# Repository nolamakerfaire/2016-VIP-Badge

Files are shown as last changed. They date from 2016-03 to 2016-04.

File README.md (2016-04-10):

# 2016 VIP Badge


The 2016 New Orleans Mini Maker Faire VIP Badge features an integrated 3.3v 8Mhz Arduino Pro Mini derivative microcontroller and USB FTDI Programmer. The badges come pre-assembled, and feature breakout headers to access the digital and analog pins as well as ground and voltage. Any 3.3v-compatible components can be used with the badge. Additionally, battery packs will be included, but they badge can also be powered by a standard USB cellphone charging battery. Finally, the Arduino Pro Mini derivative and the USB programmer snap out of the badge so you can easily integrate them into future projects.

The badge can be programmed just like a standard [Arduino Pro Mini](https://www.arduino.cc/en/Guide/ArduinoProMini). In the Arduino IDE, select Arduino Pro or Pro Mini (3.3V, 8 MHz) w/ ATmega328 from the Tools > Board menu. 

[Check out our wiki](https://github.com/nolamakerfaire/2016-VIP-Badge/wiki) for some tips on using this board.

Here's a great guide to getting started with the Arduino Pro Mini: [https://learn.sparkfun.com/tutorials/using-the-arduino-pro-mini-33v](https://learn.sparkfun.com/tutorials/using-the-arduino-pro-mini-33v)

If snapped apart, you can solder pin headers onto the USB programmer and use it exactly like the [Sparkfun FTDI Basic Breakout Board](https://www.sparkfun.com/products/9873).

## License Information

The Arduino Pro Mini derivative hardware is released under [Creative Commons Share-alike 3.0](http://creativecommons.org/licenses/by-sa/3.0/).

The FTDI Basic Breakout derivative hardware is released under [Creative Commons ShareAlike 4.0 International](https://creativecommons.org/licenses/by-sa/4.0/).

**Hardware authors:**
- Original Arduino Mini design by Team Arduino. Pro Mini design by Nathan Seidle @ SparkFun Electronics; revision work by Pete Lewis @ SparkFun Electronics
- Original FTDI Basic Breakout design by [Sparkfun](https://www.sparkfun.com/products/9873).
- 2016 VIP Badge hardware design by Scott Thomas.

Distributed as-is; no warranty is given.

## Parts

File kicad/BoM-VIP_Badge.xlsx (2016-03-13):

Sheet: Seeed BOM Format
Item No. (序号) | Reference Des (上件位置) | Qty (用量) | Catalog (分类） | Part_Description (规格描述) | Part_Value （元件值） | Part_Package （元件封装） | Manufacturers Name (使用厂牌名称) | Manufacturers Part No. (使用厂牌型号) | Distributors Name （供应商名称） | Distributors Part No. (供貨商型号) | Unit Price （单价） | Price Break To Use （价格分段的购买量） | Notes/Remark （备注）
Example（填写范例）
1 | C1, C2, C3, C4, C6, C10 | 6 | Capacitor | CAP CER 0.1UF 16V X7R 0603 | .1uF | 0603 | .1uF |  |  | 311-1088-1-ND |  |  | http://www.digikey.com/product-detail/en/CC0603KRX7R7BB104/311-1088-1-ND/302998
2 | C5, C13, C19 | 3 | Capacitor | CAP TANT 10UF 16V 10% 1206 | 10uF | 1206 | 10uF |  |  | 493-4147-1-ND |  |  | http://www.digikey.com/product-detail/en/F931C106KAA/493-4147-1-ND/2529874
3 | R2 | 1 | Resister | RES SMD 10K OHM 1% 1/16W 0603 | 10k | 0603 | 10k |  |  | A102203CT-ND |  |  | http://www.digikey.com/product-detail/en/5-1879337-9/A102203CT-ND/2728180
4 | R5, R7 | 2 | Resister | RES SMD 470 OHM 0.1% 1/16W 0603 | 470 | 0603 | 470 |  |  | A103101CT-ND |  |  | http://www.digikey.com/product-detail/en/4-1676481-7/A103101CT-ND/2728654
5 | R6, R11 | 2 | Resister | RES SMD 100 OHM 5% 1/10W 0603 | 100 | 0603 | 100 |  |  | RHM100GCT-ND |  |  | http://www.digikey.com/product-detail/en/MCR03EZPJ101/RHM100GCT-ND/628907
6 | LED1, LED2, LED3, LED4 | 4 | Diode | LED BLUE CLEAR 0603 SMD |  | 0603 |  |  |  | 160-1827-1-ND |  |  | http://www.digikey.com/scripts/DkSearch/dksus.dll?Detail&itemSeq=189541473&uq=635906125706027926
7 | S1 | 1 | OTHER | SWITCH TACTILE SPST-NO 0.05A 12V |  |  |  |  |  | EG2531CT-ND |  |  | http://www.digikey.com/product-detail/en/TL3342F160QG%2FTR/EG2531CT-ND/379004
8 | Q1 | 1 | OTHER | CER RES 8.0000MHZ 33PF SMD |  |  |  |  |  | 490-1195-1-ND |  |  | http://www.digikey.com/scripts/DkSearch/dksus.dll?Detail&itemSeq=188990760&uq=635899485135239801
9 | U1 | 1 | IC | IC MCU 8BIT 32KB FLASH 32TQFP |  | 32TQFP |  |  |  | ATMEGA328P-AU-ND |  |  | http://www.digikey.com/product-detail/en/ATMEGA328P-AU/ATMEGA328P-AU-ND/1832260
10 | U2 | 1 | IC | IC REG LDO 3.3V 0.15A SOT23-5 |  | SOT23-5 |  |  |  | 576-1259-1-ND |  |  | http://www.digikey.com/product-detail/en/MIC5205-3.3YM5-TR/576-1259-1-ND/771886
11 | U3 | 1 | IC | IC USB FS SERIAL UART 28-SSOP |  | 28-SSOP |  |  |  | 768-1007-1-ND |  |  | http://www.digikey.com/product-detail/en/FT232RL-REEL/768-1007-1-ND/1836402
12 | P1 | 1 | Connector | USB - micro B USB 2.0 Receptacle Connector 5 Position Surface Mount, Right Angle, Horizontal |  |  |  |  |  | 609-4613-1-ND |  |  | http://www.digikey.com/scripts/DkSearch/dksus.dll?Detail&itemSeq=189540028&uq=635906108665164544
1. Recommended Distributor: Digi-Key, Mouser, Avnet Express, Farnell.
2. Catalog: Capacitor,Resister,Diode,Connector,Transistor,IC,PROTECTOR CATEGORY,OTHER
3. Required Fields: Item No, Reference Des, Qty, Catalog, Part_Value, Part Package
Optional Fields: Part_Description, Manufacturers Name, Manufacturers Part No, Distributors Name, Distributors Part No, Unit Cost, Price break to use, Notes/Remark

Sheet: Sheet1
Item No. (序号) | Reference Des (上件位置) | Qty (用量) | Catalog (分类） | Part_Description (规格描述) | Part_Value （元件值） | Part_Package （元件封装） | Manufacturers Name (使用厂牌名称) | Manufacturers Part No. (使用厂牌型号) | Distributors Name （供应商名称） | Distributors Part No. (供貨商型号) | Unit Price （单价） | Price Break To Use （价格分段的购买量） | Notes/Remark （备注）
Example（填写范例）
1 | BT1 | 1 | OTHER | RETAINER COIN CELL 24.5MM SMD | Coin Cell, Retainer, 24.5mm | CR2045_SMD | Keystone Electronics | 3008 | Digikey | 3008K-ND |  |  | http://www.digikey.com/product-detail/en/3008/3008K-ND/2137861
2 | C1,C11,C12,C14,C17,C18,C19,C20,C24,C25,C28,C35 | 12 | Capacitor | 2.2u,16V, Y5V | CAP CER 2.2uF 16V Y5V 0805 | c_0805 | Samsung Electro-Mechanics America, Inc | CL21F225ZOFNNNE | Digikey | 1276-3016-1-ND |  |  | http://www.digikey.com/product-detail/en/CL21F225ZOFNNNE/1276-3016-1-ND/3891102
3 | C2,C3,C4,C5,C26,C27,C29,C31,C34 | 9 | Capacitor | 0.1u,16V, Y5V | CAP CER 0.1uF 16V Y5V 0805 | c_0805 | Kemet | C0805C104Z4VACTU | Digikey | 399-9159-1-ND |  |  | http://www.digikey.com/product-detail/en/C0805C104Z4VACTU/399-9159-1-ND/3522677
4 | C6,C9 | 2 | Capacitor | 22pF | CAP CER 22pF 16V 10% NP0 0603 | c_0805 | Kemet | C0603C220K4GACTU | Digikey | 399-9031-1-ND |  |  | http://www.digikey.com/product-detail/en/C0603C220K4GACTU/399-9031-1-ND/3522548
5 | C10 | 1 | Capacitor | 2.2u,10V, Y5V | CAP CER 2.2uF 10V Y5V 0805 | c_0805 | Murata Electronics North America | GRM21BF51C225ZA01L | Digikey | 490-1741-1-ND |  |  | http://www.digikey.com/product-detail/en/GRM21BF51C225ZA01L/490-1741-1-ND/587394
6 | C13 C15 C16 C22 C23 | 5 | Capacitor | 2.2u,25V, Y5V | CAP CER 2.2uF 25V Y5V 0805 | c_0805 | Samsung Electro-Mechanics America, Inc | CL21F225ZAFNNNE | Digikey | 1276-2874-1-ND |  |  | http://www.digikey.com/product-detail/en/CL21F225ZAFNNNE/1276-2874-1-ND/3890960
7 | C21 | 1 | Capacitor | 1u,10V, X7R | CAP CER 1uF 10V 20% X7R 0805 | c_0805 | Samsung Electro-Mechanics America, Inc | CL21B105MPFNNNE | Digikey | 1276-2933-1-ND |  |  | http://www.digikey.com/product-detail/en/CL21B105MPFNNNE/1276-2933-1-ND/3891019
8 | D1 | 1 | Diode | BAT54SW | DIODE SCHOTTKY 30V 200mA SC70 | SOT323 | NXP Semiconductors | BAT54SW,115 | Digikey | 568-1615-1-ND |  |  | http://www.digikey.com/product-detail/en/BAT54SW,115/568-1615-1-ND/763442
9 | D2 | 1 | Diode | DB2S20500L | DIODE SCHOTTKY 15V 200mA SSMINI2 | d_VMD2 | Panasonic Electronic Components - Semiconductor Products | DB2S20500L | Digikey | DB2S20500LCT-ND |  |  | http://www.digikey.com/product-detail/en/DB2S20500L/DB2S20500LCT-ND/2326091
10 | D3 | 1 | Diode | DEBUG | LED MINI TOPLED RED 630NM SMD | 2-SMD, J-Lead | OSRAM Opto Semiconductors Inc | LS M67K-J2L1-1-Z | Digikey | 475-2691-1-ND |  |  | http://www.digikey.com/product-detail/en/LS%20M67K-J2L1-1-Z/475-2691-1-ND/1938858
11 | J4 | 1 | Connector | ZIF-40-0.5 | CONN FPC/FFC 40POS .5MM HORZ SMD | ZIF-40-0.5-M | OSRAM Opto Semiconductors Inc | LG M67K-H1J2-24-Z | Digikey | 732-6012-1-ND |  |  | http://www.digikey.com/product-detail/en/687140149022/732-6012-1-ND/5047608
12 | P3 | 1 | Connector | FTDI | CONN HEADER 6POS .100 R/A 30AU | Header_FTDI | FCI | 68016-106HLF | Digikey | 609-3313-ND |  |  | http://www.digikey.com/product-detail/en/68016-106HLF/609-3313-ND/1878482
13 | Q1 | 1 | Transistor | DMG2301U-7 | MOSFET P-CH 20V 2.5A SOT23 | SOT23-3 | Diodes Inc | DMG2301U-7 | Digikey | DMG2301U-7DICT-ND |  |  | http://www.digikey.com/product-detail/en/DMG2301U-7/DMG2301U-7DICT-ND/2179851
14 | Q2 Q4 Q5 Q6 | 4 | Transistor | 2N7002KW | MOSFET NCH 60V 310mA SOT323 | SOT323 | Fairchild Semiconductor | 2N7002KW | Digikey | 2N7002KWCT-ND |  |  | http://www.digikey.com/product-detail/en/2N7002KW/2N7002KWCT-ND/3907885
15 | Q3 Q7 | 2 | Transistor | BSS84W | MOSFET P-CH 50V 130mA SC70-3 | SOT323 | Diodes Inc | BSS84W-7-F | Digikey | BSS84W-FDICT-ND |  |  | http://www.digikey.com/product-detail/en/BSS84W-7-F/BSS84W-FDICT-ND/806569
16 | R1 | 1 | Resister | 33k, 5% | RES 33k OHM 1/8W 5% 0805 SMD | r_0805 | Yageo | RC0805JR-0733KL | Digikey | 311-33KARCT-ND |  |  | http://www.digikey.com/product-detail/en/RC0805JR-0733KL/311-33KARCT-ND/731261
17 | R4 R5 R6 R7 R13 R16 | 6 | Resister | 10k, 5% | RES 10k OHM 1/8W 5% 0805 | r_0805 | Stackpole Electronics Inc | RMCF0805JT10K0 | Digikey | RMCF0805JT10K0CT-ND |  |  | http://www.digikey.com/product-detail/en/RMCF0805JT10K0/RMCF0805JT10K0CT-ND/1942577
18 | R9 | 1 | Resister | 2k, 5% | RES 2.0k OHM 1/8W 5% 0805 SMD | r_0805 | Yageo | RC0805JR-072KL | Digikey | 311-2.0KARCT-ND |  |  | http://www.digikey.com/product-detail/en/RC0805JR-072KL/311-2.0KARCT-ND/731215
19 | R10 R11 R12 | 3 | Resister | 100k, 5% | RES 100k OHM 1/8W 5% 0805 | r_0805 | Stackpole Electronics Inc | RMCF0805JT100K | Digikey | RMCF0805JT100KCT-ND |  |  | http://www.digikey.com/product-detail/en/RMCF0805JT100K/RMCF0805JT100KCT-ND/1942592
20 | R14 | 1 | Resister | 1k5, 5% | RES 1k5 OHM 1/8W 5% 0805 | r_0805 | Stackpole Electronics Inc | RMCF0805JT1K50 | Digikey | RMCF0805JT1K50CT-ND |  |  | http://www.digikey.com/product-detail/en/RMCF0805JT1K50/RMCF0805JT1K50CT-ND/1942560
21 | SD1 | 1 | Connector | Micro SD Card Socket | SD_CARD_MICRO | SD_Micro | Amphenol | 101-00303-68 | Digikey | 101-00303-68-1-ND |  |  | http://www.digikey.com/product-detail/en/101-00303-68/101-00303-68-1-ND/2187100
22 | SW1, SW2, SW3, SW4, SW5 | 5 | OTHER | UP | SW TACT SPST-NO 0.05A 12V | SW-PB | CTS Electrocomponents | 222AMVBAR | Digikey | CT3088CT-ND |  |  | http://www.digikey.com/product-detail/en/222AMVBAR/CT3088CT-ND/5227995
23 | SW6 | 1 | OTHER | SW_ON | SWITCH SLIDE SPDT 300MA 4V | SW_SLIDE | Copal Electronics | CUS-12TB | Digikey | 563-1102-1-ND |  |  | http://www.digikey.com/product-detail/en/CUS-12TB/563-1102-1-ND/1124231
24 | U2 | 1 | IC | ATMEGA328-AU-ND | IC MCU 8BIT 32KB FLASH 32TQFP | TQFP32 | Atmel | ATMEGA328-AU | Digikey | ATMEGA328-AU-ND |  |  | http://www.digikey.com/product-detail/en/ATMEGA328-AU/ATMEGA328-AU-ND/2271029
25 | U3 | 1 | IC | MCP1700T-33 | IC REG LDO 3.3V .25A SOT23-3 | SOT23 | Microchip Technology | MCP1700T-3302E/TT | Digikey | MCP1700T3302ETTCT-ND |  |  | http://www.digikey.com/product-detail/en/MCP1700T-3302E%2FTT/MCP1700T3302ETTCT-ND/652677
26 | U4 | 1 | IC | TXS0108 | IC 8BIT NON-INV TRANSLTR 20TSSOP | SO20L | Texas Instruments | TXS0108EPWR | Digikey | 296-23011-1-ND |  |  | http://www.digikey.com/product-detail/en/TXS0108EPWR/296-23011-1-ND/1775304
27 | X1 | 1 | OTHER | 8MHz | CRYSTAL 8.0MHz 8pF SMD | 2-SMD | NDK | NX8045GB-8.000000MHZ | Digikey | 644-1018-1-ND |  |  | http://www.digikey.com/product-detail/en/NX8045GB-8.000000MHZ/644-1018-1-ND/1128890

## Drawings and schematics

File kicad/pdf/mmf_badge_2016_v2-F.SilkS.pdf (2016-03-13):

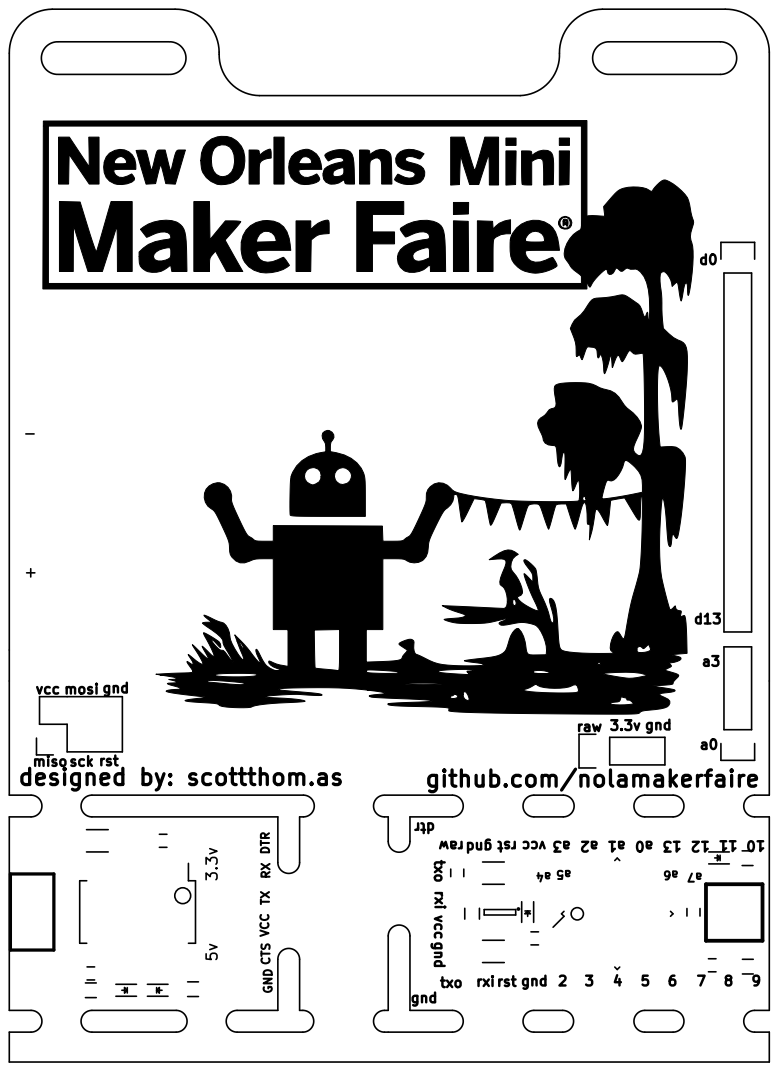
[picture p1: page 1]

d0 d13 miso sck rst vcc mosi gnd

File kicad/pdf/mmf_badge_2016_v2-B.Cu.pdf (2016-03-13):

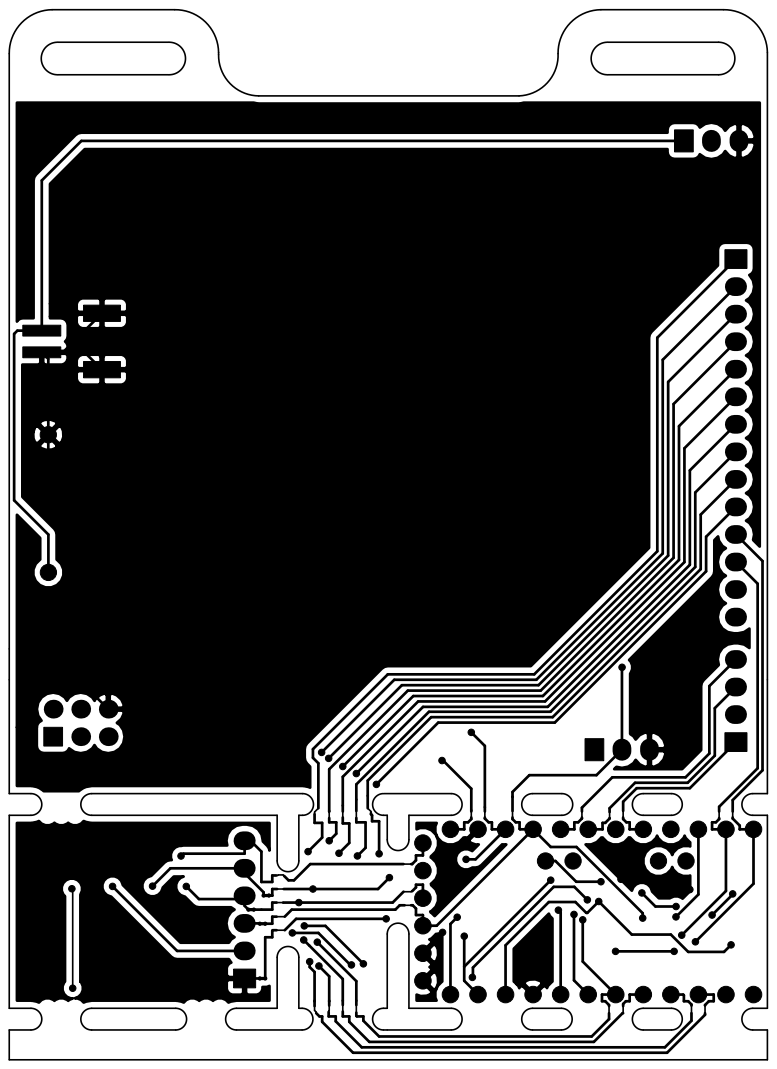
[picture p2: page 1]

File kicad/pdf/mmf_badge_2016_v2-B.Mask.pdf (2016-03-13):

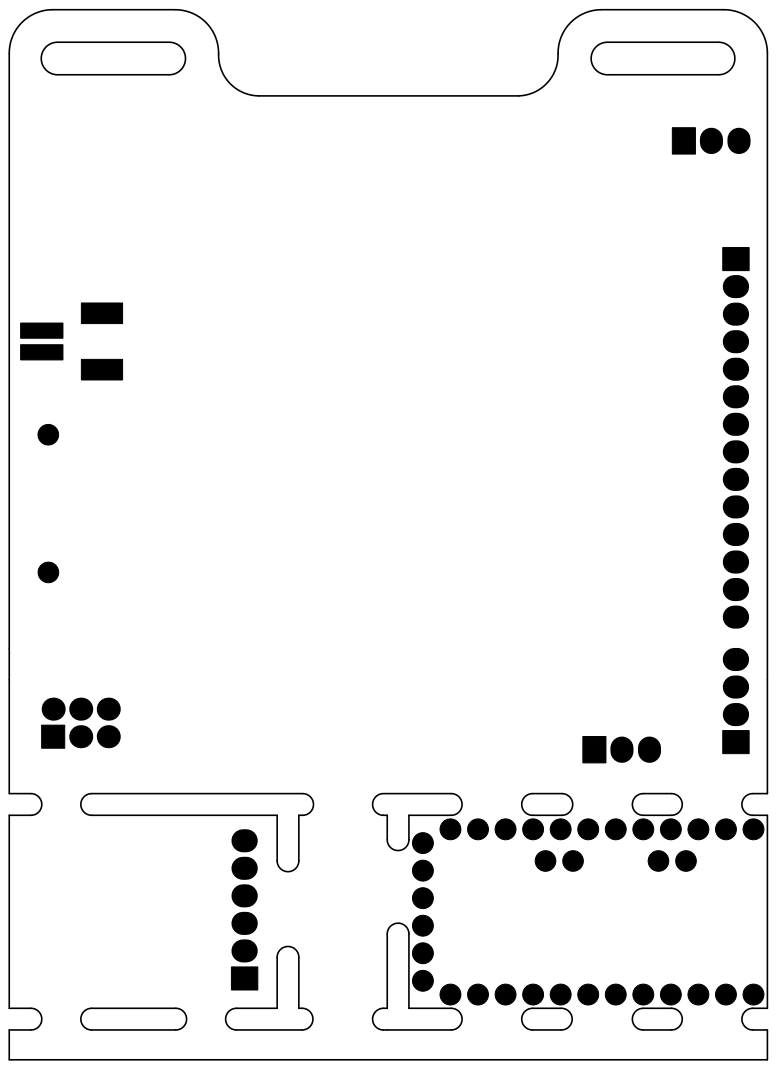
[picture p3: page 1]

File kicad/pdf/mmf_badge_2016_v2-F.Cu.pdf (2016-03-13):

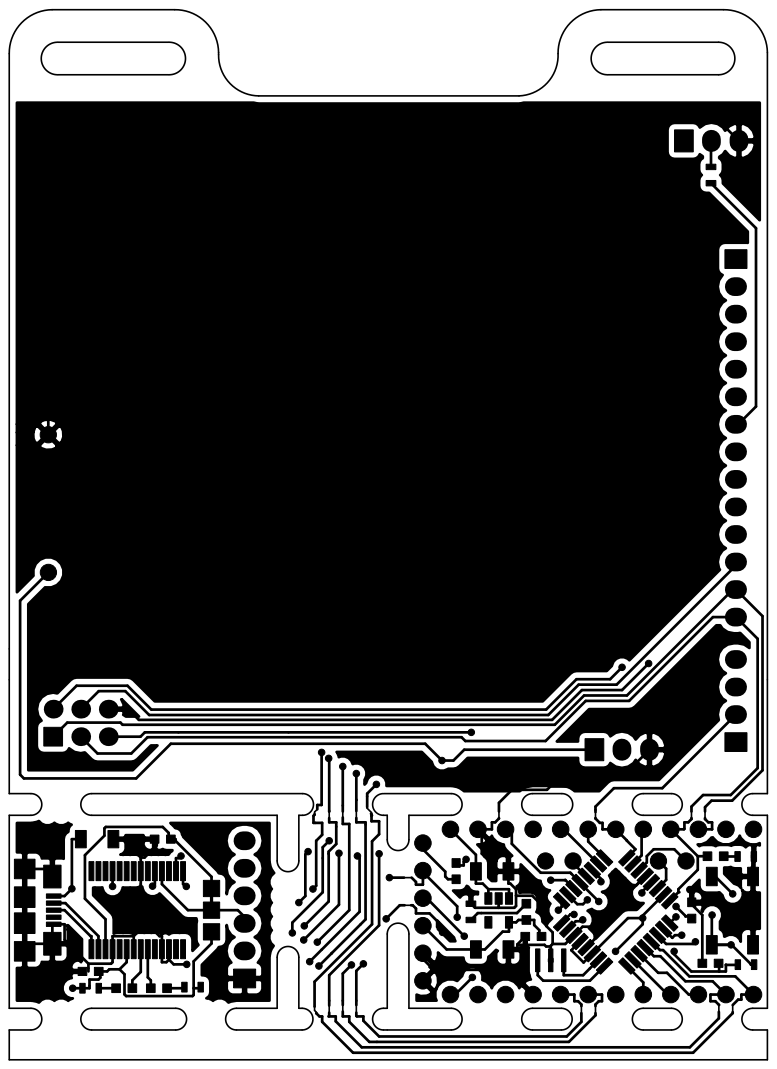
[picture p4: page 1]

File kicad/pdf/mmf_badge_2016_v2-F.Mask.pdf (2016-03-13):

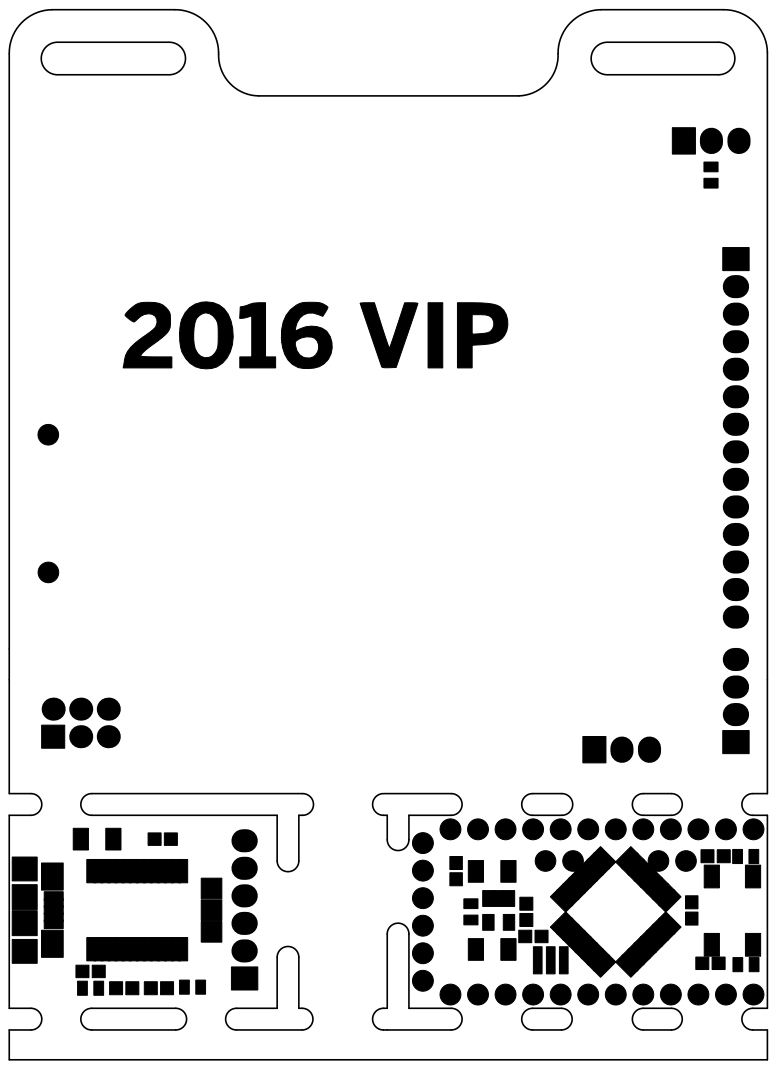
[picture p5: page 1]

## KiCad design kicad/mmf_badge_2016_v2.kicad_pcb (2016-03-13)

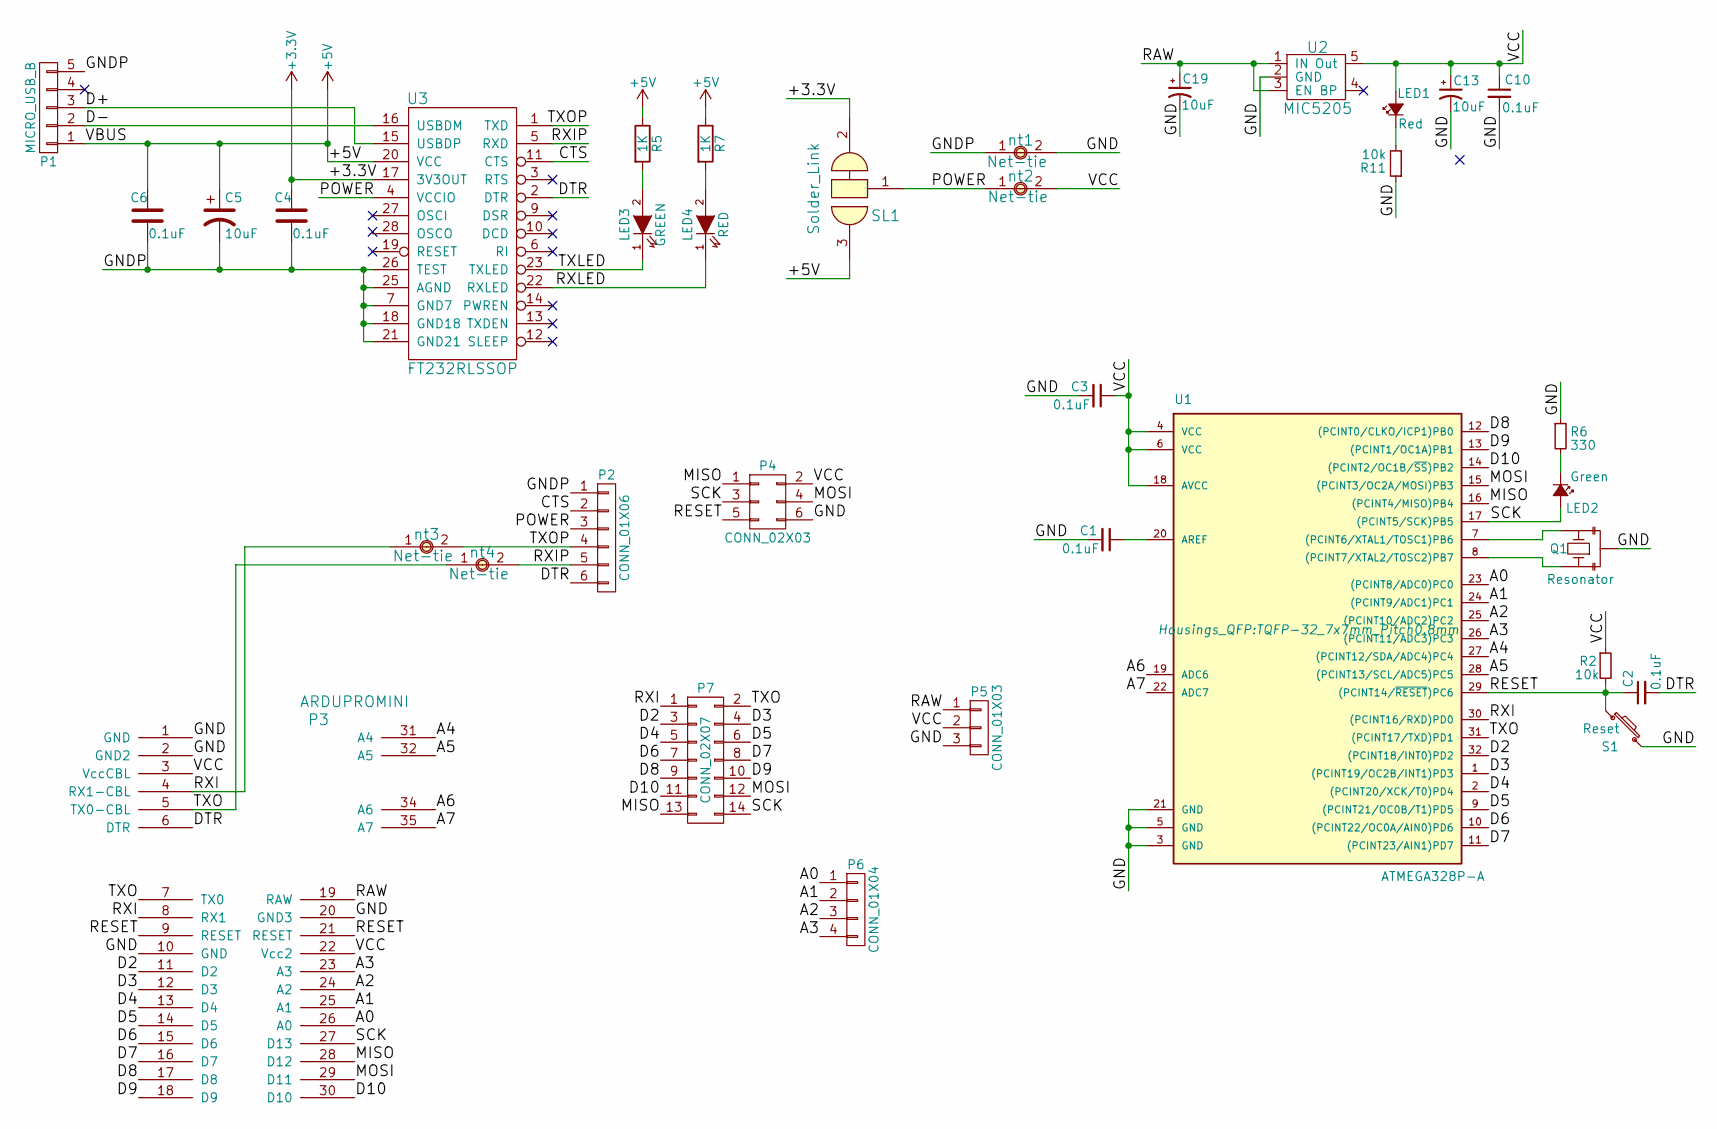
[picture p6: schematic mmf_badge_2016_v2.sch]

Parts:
C1, C2, C3, C4, C6, C10: 0.1uF; C_0402
C5, C13, C19: 10uF; C_1206
LED1: Red; LED-0603
LED2: Green; LED-0603
LED3: GREEN; LED-0603
LED4: RED; LED-0603
P1: MICRO_USB_B; USB_Micro-B_SMD
P2: CONN_01X06; Pin_Header_Straight_1x06
P3: ARDUPROMINI; ArduProMini
P4: CONN_02X03; Pin_Header_Straight_2x03
P5: CONN_01X03; Pin_Header_Straight_1x03
P6: CONN_01X04; Pin_Header_Straight_1x04
P7: CONN_02X07; Pin_Header_Straight_2x07
Q1: Resonator; SMD_Resonator
R2, R11: 10k; R_0402
R5, R7: 1K; R_0402
R6: 330; R_0402
S1: Reset; SW_SPST_EVPBF
SL1: Solder_Link
U1: ATMEGA328P-A; TQFP-32_7x7mm_Pitch0.8mm
U2: MIC5205; SOT-23-5
U3: FT232RLSSOP; SSOP-28_5.3x10.2mm_Pitch0.65mm
nt1, nt2, nt3, nt4: Net-tie; Net_tie

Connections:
+3V3: C4.1, SL1.2, U3.17 (3V3OUT)
+5V: C5.1, C6.1, P1.1, R5.1, R7.1, SL1.3, U3.20 (VCC)
/A0: P3.26 (A0), P6.1, U1.23 ((PCINT8/ADC0)PC0)
/A1: P3.25 (A1), P6.2, U1.24 ((PCINT9/ADC1)PC1)
/A2: P3.24 (A2), P6.3, U1.25 ((PCINT10/ADC2)PC2)
/A3: P3.23 (A3), P6.4, U1.26 ((PCINT11/ADC3)PC3)
/A4: P3.31 (A4), U1.27 ((PCINT12/SDA/ADC4)PC4)
/A5: P3.32 (A5), U1.28 ((PCINT13/SCL/ADC5)PC5)
/A6: P3.34 (A6), U1.19 (ADC6)
/A7: P3.35 (A7), U1.22 (ADC7)
/CTS: P2.2, U3.11 (CTS)
/D2: P3.11 (D2), P7.3, U1.32 ((PCINT18/INT0)PD2)
/D3: P3.12 (D3), P7.4, U1.1 ((PCINT19/OC2B/INT1)PD3)
/D4: P3.13 (D4), P7.5, U1.2 ((PCINT20/XCK/T0)PD4)
/D5: P3.14 (D5), P7.6, U1.9 ((PCINT21/OC0B/T1)PD5)
/D6: P3.15 (D6), P7.7, U1.10 ((PCINT22/OC0A/AIN0)PD6)
/D7: P3.16 (D7), P7.8, U1.11 ((PCINT23/AIN1)PD7)
/D8: P3.17 (D8), P7.9, U1.12 ((PCINT0/CLKO/ICP1)PB0)
/D9: P3.18 (D9), P7.10, U1.13 ((PCINT1/OC1A)PB1)
/D10: P3.30 (D10), P7.11, U1.14 ((PCINT2/OC1B/~SS~)PB2)
/D+: P1.3, U3.15 (USBDP)
/D-: P1.2, U3.16 (USBDM)
/DTR: C2.2, P2.6, P3.6 (DTR), U3.2 (DTR)
/GND: C1.2, C3.2, C10.2, C13.2, C19.2, P3.1 (GND), P3.2 (GND2), P3.10 (GND), P3.20 (GND3), P4.6, P5.3, Q1.2 (GND), R6.1, R11.1, S1.2, U1.3 (GND), U1.5 (GND), U1.21 (GND), U2.2 (GND), nt1.2
/GNDP: C4.2, C5.2, C6.2, P1.5, P2.1, U3.7 (GND7), U3.18 (GND18), U3.21 (GND21), U3.25 (AGND), U3.26 (TEST), nt1.1
/MISO: P3.28 (D12), P4.1, P7.13, U1.16 ((PCINT4/MISO)PB4)
/MOSI: P3.29 (D11), P4.4, P7.12, U1.15 ((PCINT3/OC2A/MOSI)PB3)
/POWER: P2.3, SL1.1, U3.4 (VCCIO), nt2.1
/RAW: C19.1, P3.19 (RAW), P5.1, U2.1 (IN), U2.3 (EN)
/RESET: C2.1, P3.9 (RESET), P3.21 (RESET), P4.5, R2.2, S1.1, U1.29 ((PCINT14/~RESET~)PC6)
/RXI: P3.4 (RX1-CBL), P3.8 (RX1), P7.1, U1.30 ((PCINT16/RXD)PD0), nt3.1
/RXIP: P2.5, U3.5 (RXD), nt4.2
/RXLED: LED4.1 (K), U3.22 (RXLED)
/SCK: LED2.2 (A), P3.27 (D13), P4.3, P7.14, U1.17 ((PCINT5/SCK)PB5)
/TXLED: LED3.1 (K), U3.23 (TXLED)
/TXO: P3.5 (TX0-CBL), P3.7 (TX0), P7.2, U1.31 ((PCINT17/TXD)PD1), nt4.1
/TXOP: P2.4, U3.1 (TXD), nt3.2
/VCC: C3.1, C10.1, C13.1, LED1.2 (A), P3.3 (VccCBL), P3.22 (Vcc2), P4.2, P5.2, R2.1, U1.4 (VCC), U1.6 (VCC), U1.18 (AVCC), U2.5 (Out), nt2.2
unnamed: C1.1, U1.20 (AREF)
unnamed: LED1.1 (K), R11.2
unnamed: LED2.1 (K), R6.2
unnamed: LED3.2 (A), R5.2
unnamed: LED4.2 (A), R7.2
unnamed: Q1.1, U1.8 ((PCINT7/XTAL2/TOSC2)PB7)
unnamed: Q1.3, U1.7 ((PCINT6/XTAL1/TOSC1)PB6)

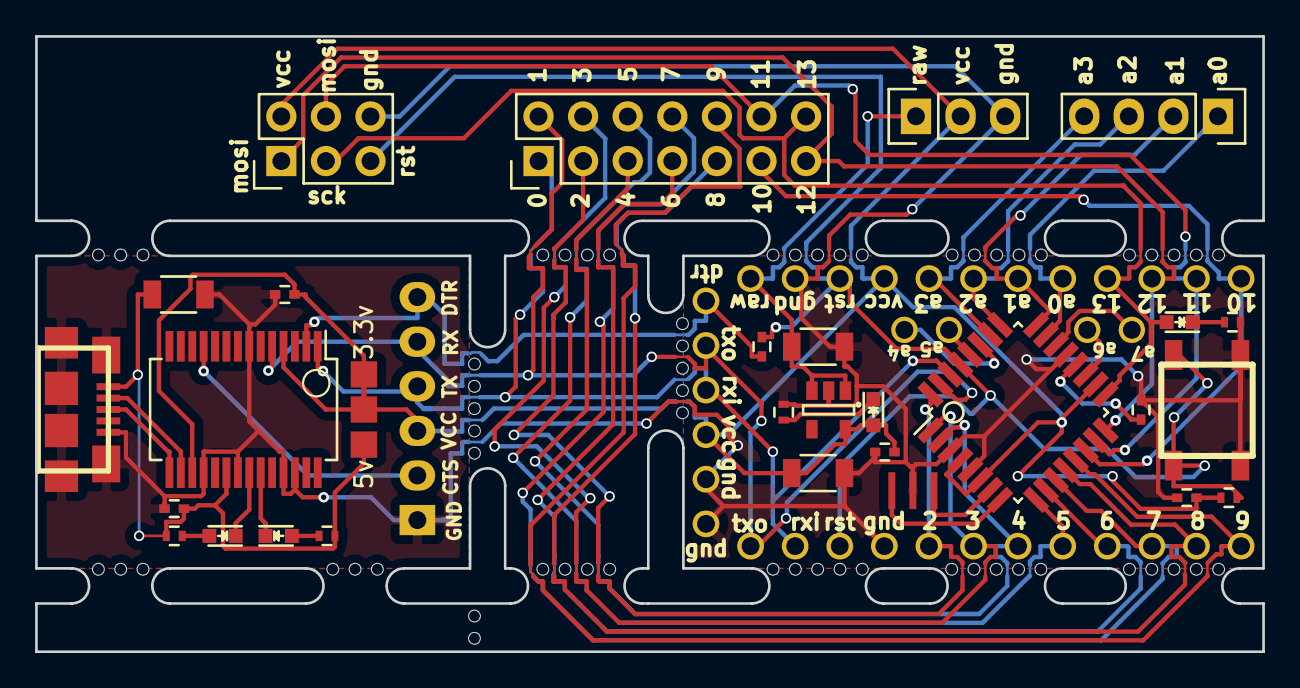
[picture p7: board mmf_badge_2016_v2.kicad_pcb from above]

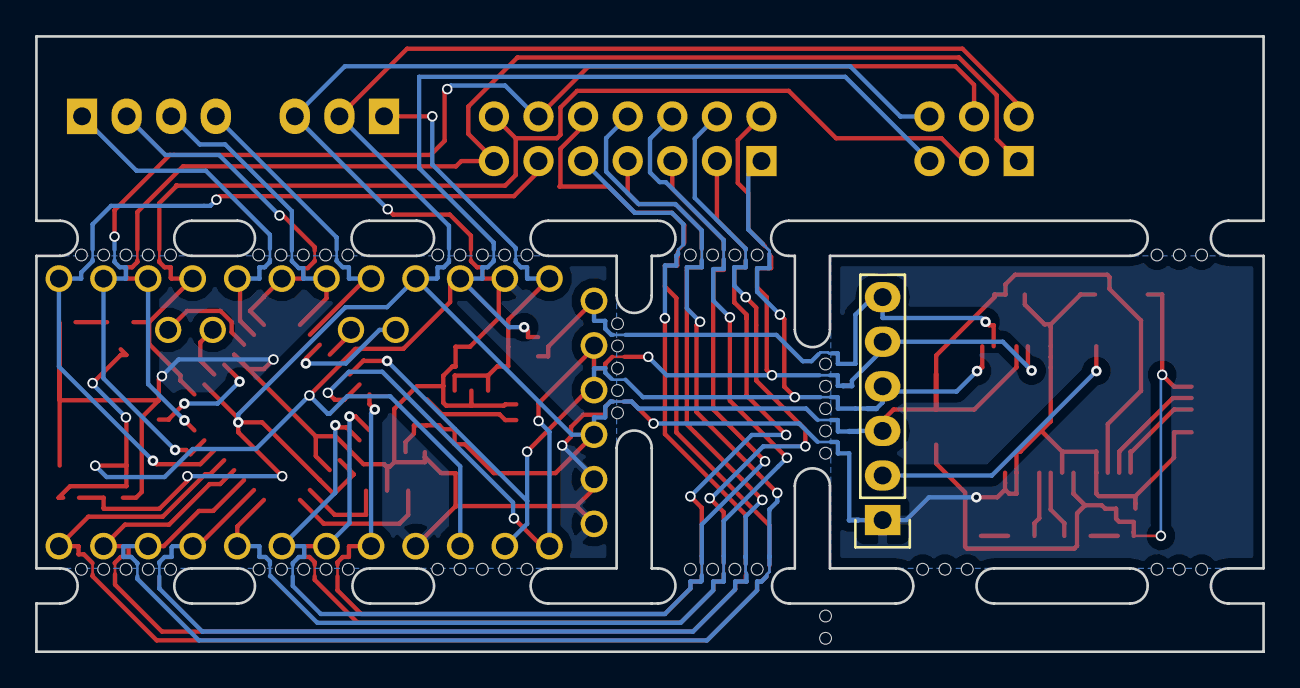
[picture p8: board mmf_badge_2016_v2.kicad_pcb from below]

Board: 2 copper layers, 69.9 x 35.1 mm, 35 parts (5 on the bottom side), 45 nets.

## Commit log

2016-03-13 Cleaning up directory structure
    [mmf_badge_2016_v2.dsn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]
2016-03-13 Added BoM
    [BoM-VIP_Badge.xlsx]
